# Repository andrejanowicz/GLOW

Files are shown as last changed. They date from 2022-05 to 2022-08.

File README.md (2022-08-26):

# GLOW preamp board for G&L L-2000 and L-2500 Tribute basses

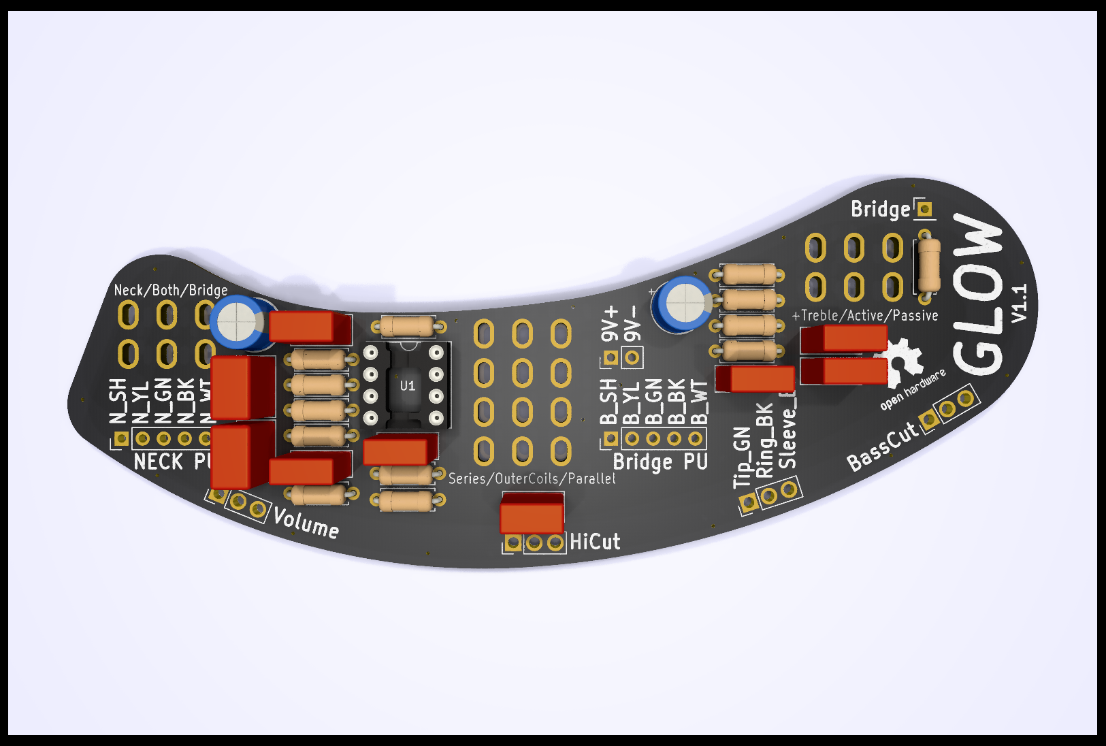
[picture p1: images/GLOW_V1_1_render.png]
</br>

### you might now the situation

>You’re at band rehearsal, playing your beautiful L2000 in active mode with crisp treble boost (that's how its done, right?), as you notice the dreaded hissing of a dying battery. You switch to passive mode with the swiftness of a hungry cheetah, but the guitar player already gives you the look. Of course he has noticed. He always does. You did only pretend to notice the pre CBS mojo of his '62 Strat though. Take that, Mr. all-passive-signal-path.
>
>As the song is done, you put the bass away. No way you’re changing the battery right here on the spot, with all those witnesses. This dirty secret must stay between the L2000 and you, they must not know! They have no idea that this is Leo’s actual masterpiece, not some overpriced 60s guitar. You touch the little switches, toggle them one by one, the click is as satisfying as on the day you brought it home. It takes some time to understand them, sure. To you, they are no mystery. Of course there are a lot of wires needed for all this flexibility, only a fool would not understand that. „Volume - Volume - Tone.. Pathetic!“ you mumble to yourself a little louder than intended. By now the drummer also looks at you. You go home. You wait until everybody is asleep and start silently searching for the screwdriver. You bite your tongue as you open the electronics compartment. You just can’t stand that mess. This instrument deserves better. You change the battery, put the bass aside and check to what dimensions the lead time for Wal MK2‘s has grown by now. You drool over that sweet, clean and well organized electronics box, that PCB: per-fec-tion. If you only bought one eight years ago, when you had the chance. While contemplating live decisions you hear a soft voice: Is everything okay, honey? It’s late, are you looking at bass guitars on the internet again? "Damn right I am, and I think I might have a plan" you say as you look up without blinking your eyes.

## Features

- single PCB with elegant black soldermask
- directly connected toggle switches, no extra wires
- additional single coil setting using only outer coils (K-Mod)
- original preamp circuitry using highest quality components:
- Wima MKP/FKP foil capacitors, Panasonic FC electrolytic capacitors, Yageo 1% resistors
- compatible with original LM4250 or alternatively TL061 op-amps
- fully open source KiCad project (CC BY-NC-SA 4.0)
- fits Tribute models made in Korea and Indonesia (no guarantee)
- banana shaped

## PCB top
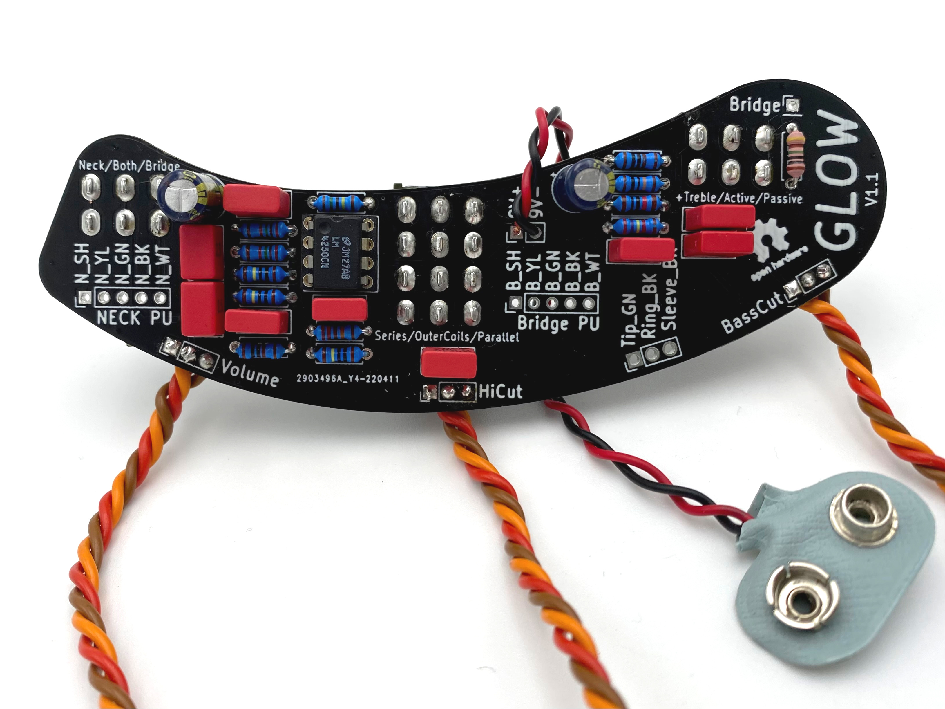
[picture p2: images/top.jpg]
</br>
## PCB bottom
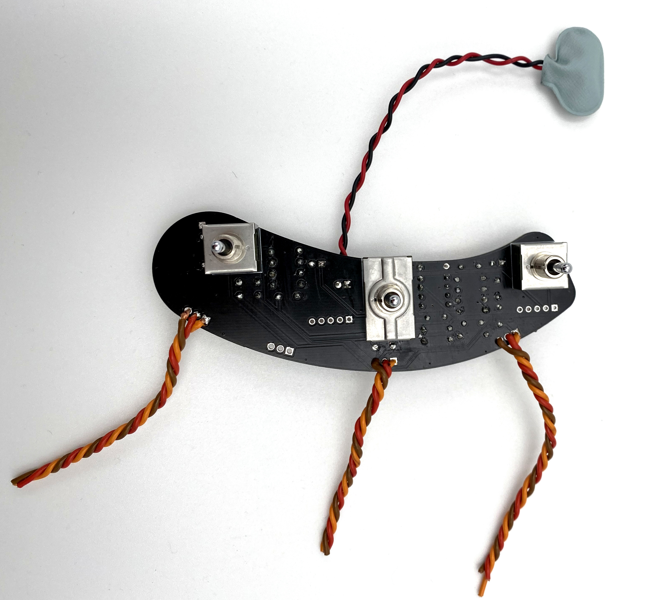
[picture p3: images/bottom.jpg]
</br>
## installed
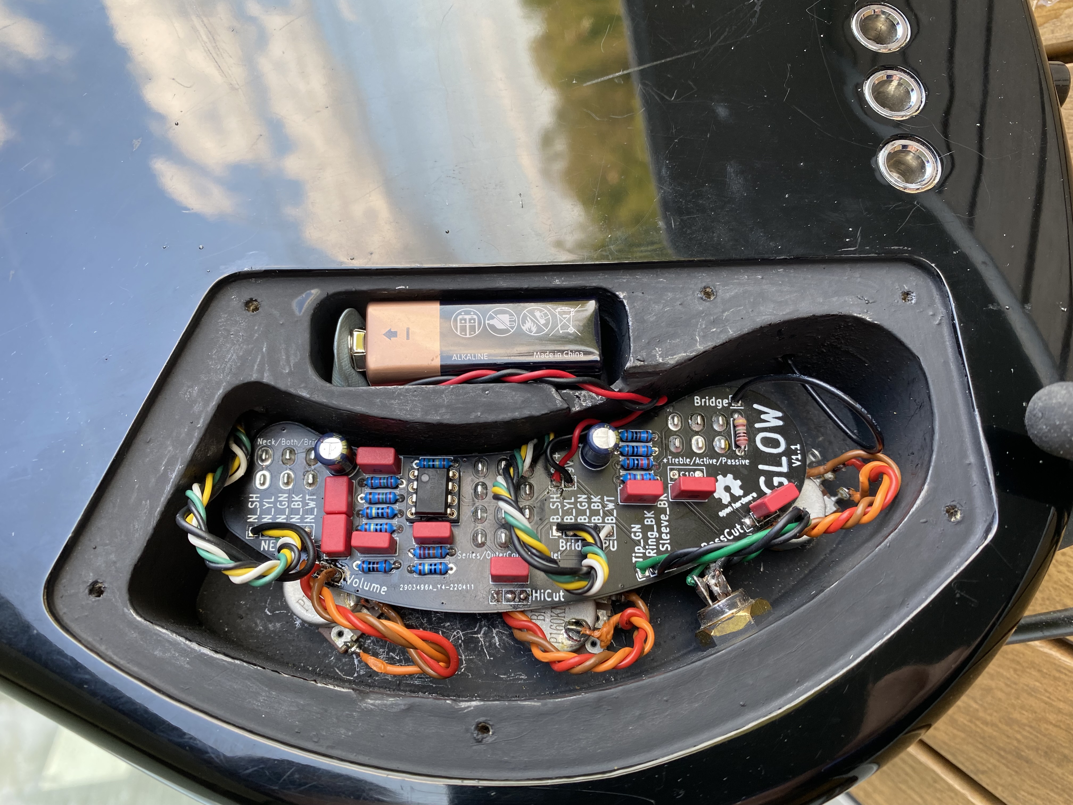
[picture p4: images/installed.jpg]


I give absolutely no guarantee that the PCB and most important the position of the toggle switches will fit your bass. Glow was succesfully installed by me and others in four and five string indonesian and korean Tribute models (L-2000 and L-2500). Fit in USA models is unknown. It does <b>not</b> fit models with sheet metal cover on front/knob side. 
The stock 24mm pots are interfering with GLOW PCB and you need to use 16mm pots with at least 7mm thread length. For more information see BOM document.

## Drill hole position check
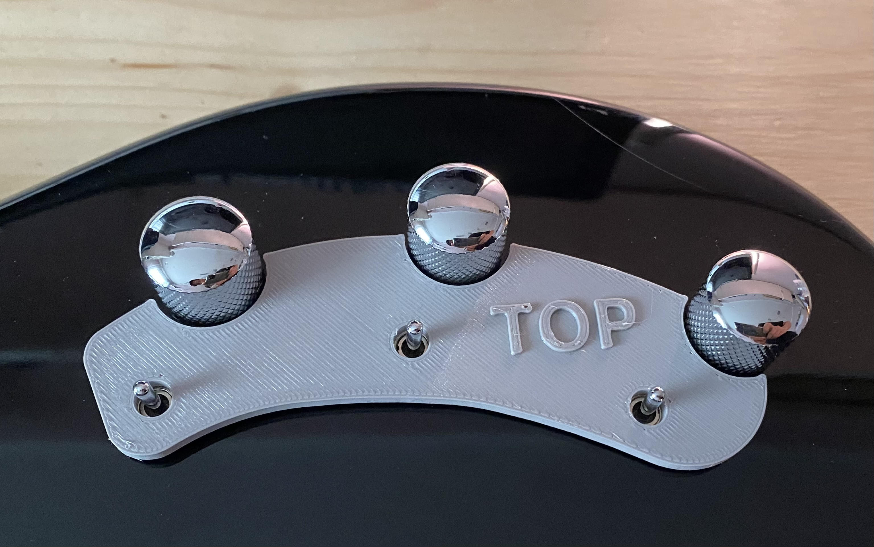
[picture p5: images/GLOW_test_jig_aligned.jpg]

You can upfront assess the fit by 3D printing GLOW_test_jig.stl and align the jig with the position of your toggle switches.

## Thanks
This project would have been much harder without the extensive information found on [bassesbyleo.com](https://www.bassesbyleo.com/) .

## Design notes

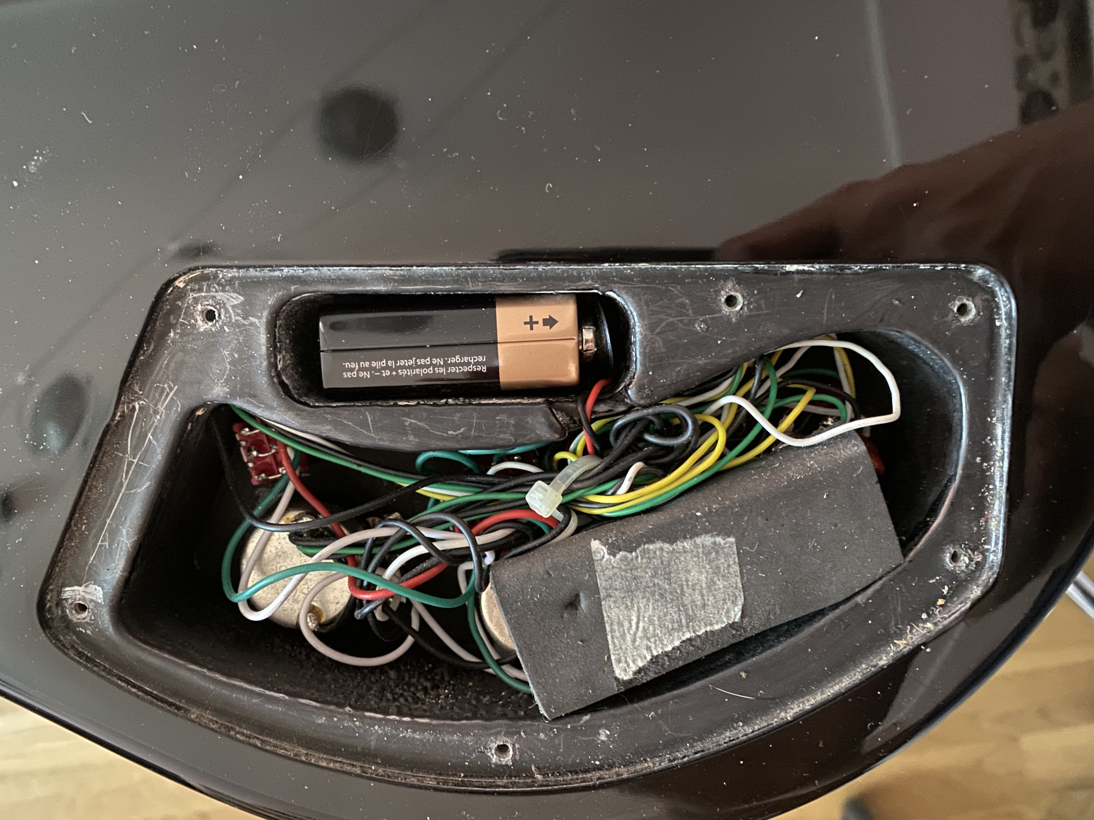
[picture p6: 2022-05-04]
images/before.jpg

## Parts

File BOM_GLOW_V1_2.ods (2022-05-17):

Date: | Wed 04 May 2022 04:34:23 PM CEST
Tool: | Eeschema 6.0.4-6f826c9f35~116~ubuntu20.04.1
Generator: | /usr/share/kicad/plugins/bom_csv_grouped_by_value_with_fp.py
Component Count: | 31
Ref | Qnty | Value | Cmp name | Footprint | Description | Vendor
C1, C8, | 2 | C_Polarized 10uF | C_Polarized | Capacitor_THT:CP_Radial_D6.3mm_P2.50mm | Polarized capacitor | Panasonic | EEU-FC2A100B
C2, | 1 | 220p | C | Capacitor_THT:C_Rect_L7.2mm_W4.5mm_P5.00mm_FKS2_FKP2_MKS2_MKP2 | Unpolarized capacitor | WIMA | FKP2D002201D00HSSD
C3, | 1 | 220p ( originally 200p) | C | Capacitor_THT:C_Rect_L7.2mm_W4.5mm_P5.00mm_FKS2_FKP2_MKS2_MKP2 | Unpolarized capacitor | WIMA | FKP2D002201D00HSSD
C4, C7, | 2 | 47n | C | Capacitor_THT:C_Rect_L7.2mm_W3.5mm_P5.00mm_FKS2_FKP2_MKS2_MKP2 | Unpolarized capacitor | WIMA | MKP2D024701C00JO00
C5, | 1 | 10n | C | Capacitor_THT:C_Rect_L7.2mm_W3.0mm_P5.00mm_FKS2_FKP2_MKS2_MKP2 | Unpolarized capacitor | WIMA | MKP2D021001B00JC00
C6, C10, | 2 | 1n | C | Capacitor_THT:C_Rect_L7.2mm_W3.0mm_P5.00mm_FKS2_FKP2_MKS2_MKP2 | Unpolarized capacitor | WIMA | MKP2G011001B00JSSD
C9, | 1 | 15n | C | Capacitor_THT:C_Rect_L7.2mm_W3.0mm_P5.00mm_FKS2_FKP2_MKS2_MKP2 | Unpolarized capacitor | WIMA | MKP2D021501B00JSSD
C11, | 1 | 2,2n | C | Capacitor_THT:C_Rect_L7.2mm_W3.0mm_P5.00mm_FKS2_FKP2_MKS2_MKP2 | Unpolarized capacitor | WIMA | MKP2J012201B00KSSD
R1, R2, | 2 | 21.5k | R | Resistor_THT:R_Axial_DIN0207_L6.3mm_D2.5mm_P7.62mm_Horizontal | Resistor | YAGEO | MFR-25FTE-21K5
R3, R4, R8, | 3 | 1M | R | Resistor_THT:R_Axial_DIN0207_L6.3mm_D2.5mm_P7.62mm_Horizontal | Resistor | YAGEO | MFR-25FTE-1M
R5, R9, | 2 | 1k | R | Resistor_THT:R_Axial_DIN0207_L6.3mm_D2.5mm_P7.62mm_Horizontal | Resistor | YAGEO | MFR-25FTE-1K
R6, | 1 | 1.5M | R | Resistor_THT:R_Axial_DIN0207_L6.3mm_D2.5mm_P7.62mm_Horizontal | Resistor | YAGEO | MFR-25FTE-1M5
R7, | 1 | 221K | R | Resistor_THT:R_Axial_DIN0207_L6.3mm_D2.5mm_P7.62mm_Horizontal | Resistor | YAGEO | MFR-25FTE-221K
R10, | 1 | 100k | R | Resistor_THT:R_Axial_DIN0207_L6.3mm_D2.5mm_P7.62mm_Horizontal | Resistor | YAGEO | MFR-25FTE-100K
R11, | 1 | 10K | R | Resistor_THT:R_Axial_DIN0207_L6.3mm_D2.5mm_P7.62mm_Horizontal | Resistor | YAGEO | MFR-25FTE-10K
R12, | 1 | 27.4k | R | Resistor_THT:R_Axial_DIN0207_L6.3mm_D2.5mm_P7.62mm_Horizontal | Resistor | YAGEO | MFR-25FTE-27K4
R13, | 1 | 10M | R | Resistor_THT:R_Axial_DIN0207_L6.3mm_D2.5mm_P7.62mm_Horizontal | Resistor | YAGEO | MFR-25FTE-10M
S1, S3, | 2 | 2PDT ON,ON,ON | 2PDT ON,ON,ON | Switch_toggle:DPDT M2044SS1W01 | Toggle Switch | NKK Switches | M2024SS1W01
S2, | 1 | 4PDT ON,ON,ON | 4PDT ON,ON,ON | G&L:4PDT M2044SS1W01 | Toggle Switch | NKK Switches | M2044SS1W01
U1, | 1 | LM4250 | LM4250 | Package_DIP:DIP-8_W7.62mm_Socket | Programmable Operational Amplifier, DIP-8/SOIC-8 | National Semiconductor | LM4250
Volume | 1 | A250k |  |  | Volume pot | Bourns | PDB181-GTR01-254A2
HiCut | 1 | A250k |  |  | HighCut pot | Bourns | PDB181-GTR01-254A2
BassCut | 1 | B500K |  |  | BassCut pot | Bourns | PDB181-GTR01-504B0

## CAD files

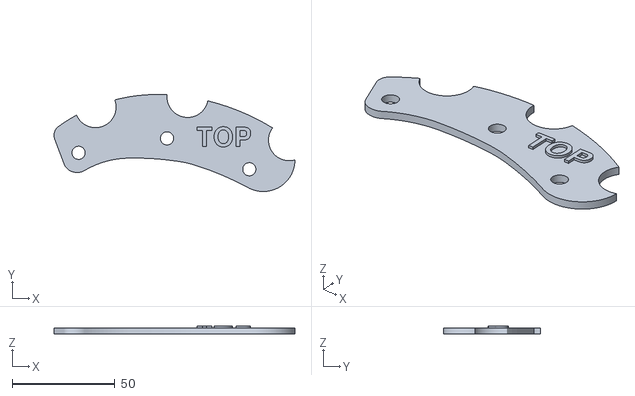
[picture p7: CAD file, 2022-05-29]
GLOW_test_jig.stl
117.1 x 47.2 x 4.00

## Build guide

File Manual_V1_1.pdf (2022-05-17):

GLOW V1.1 Assembly Manual P 1/15 - github.com/andrejanowicz/glow

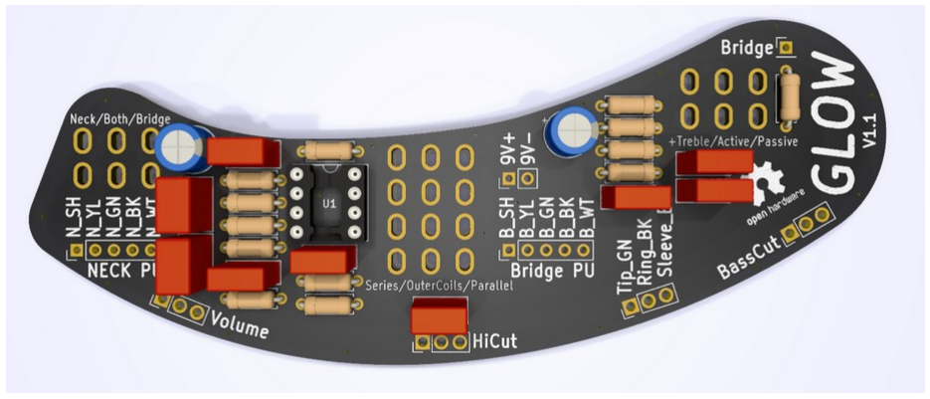
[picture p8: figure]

## Connection overview

PCB | connect to | color
N_SH | Neck cavity shield | black
N_YL | Neck pickup upper coil start | yellow
N_GN | Neck pickup upper coil finish | green
N_BK | Neck pickup lower coil finish | black
N_WT | Neck pickup lower coil start | white
B_SH | Bridge cavity shield | black
B_YL | Bridge pickup upper coil start | yellow
B_GN | Bridge pickup upper coil finish | green
B_BK | Bridge pickup lower coil finish | black
B_WT | Bridge pickup lower coil start | white
Tip_GN | Audio jack tip | green
Ring_BK | Audio jack ring | black
Sleeve_BK | Audio jack sleeve | black
9V+ | Battery positive | red
9V- | Battery negative | black
Bridge | Bridge ground | black
Volume 1 | Pot A250K / A500K pin 1 | orange
Volume 2 | Pot A250K / A500K pin 2 | red
Volume 3 | Pot A250K / A500K pin 3 + housing | brown
HiCut 1 | Pot A250K / A500K housing | orange
HiCut 2 | Pot A250K / A500K pin 2 | red
HiCut 3 | Pot A250K / A500K pin 3 | brown
BassCut 1 | Pot C500K / B500K pin 1 | orange
BassCut 2 | Pot C500K / B500K pin 2 | red
BassCut 3 | Pot C500K / B500K housing | brown

GLOW V1.1 Assembly Manual P 2/15

## PCB fit test

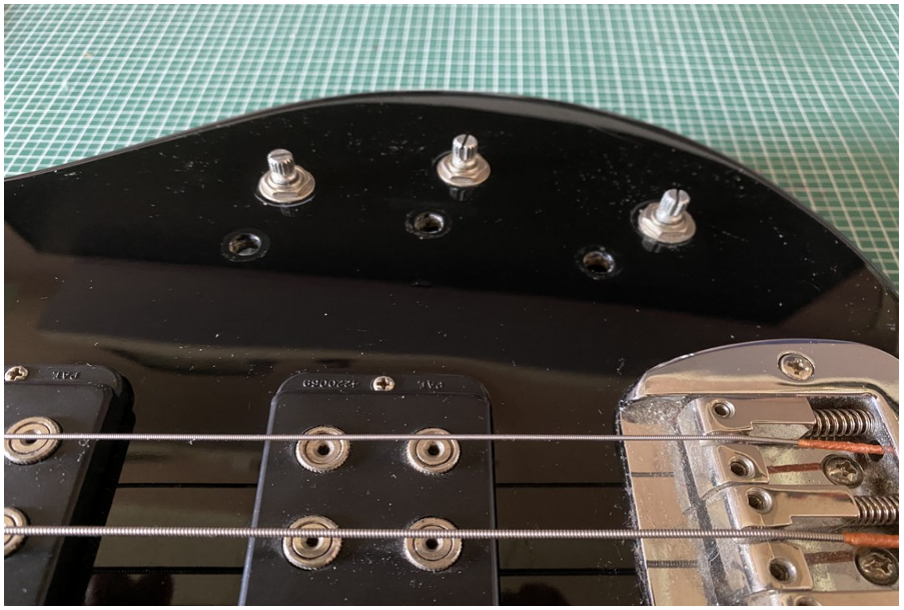
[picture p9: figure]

Illustration 1: remove knobs on all three pots. Unscrew the nuts of the three toggle switches and push toggle switches into the electronics compartment.

GLOW V1.1 Assembly Manual P 3/15

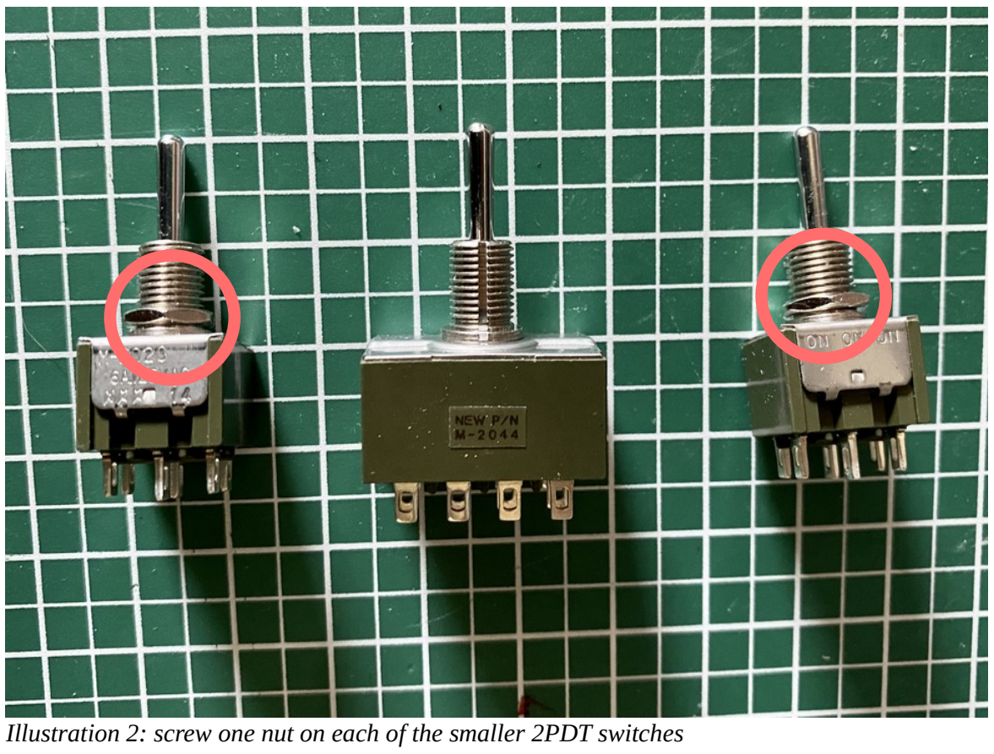
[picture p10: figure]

Illustration 2: screw one nut on each of the smaller 2PDT switches

GLOW V1.1 Assembly Manual P 4/15

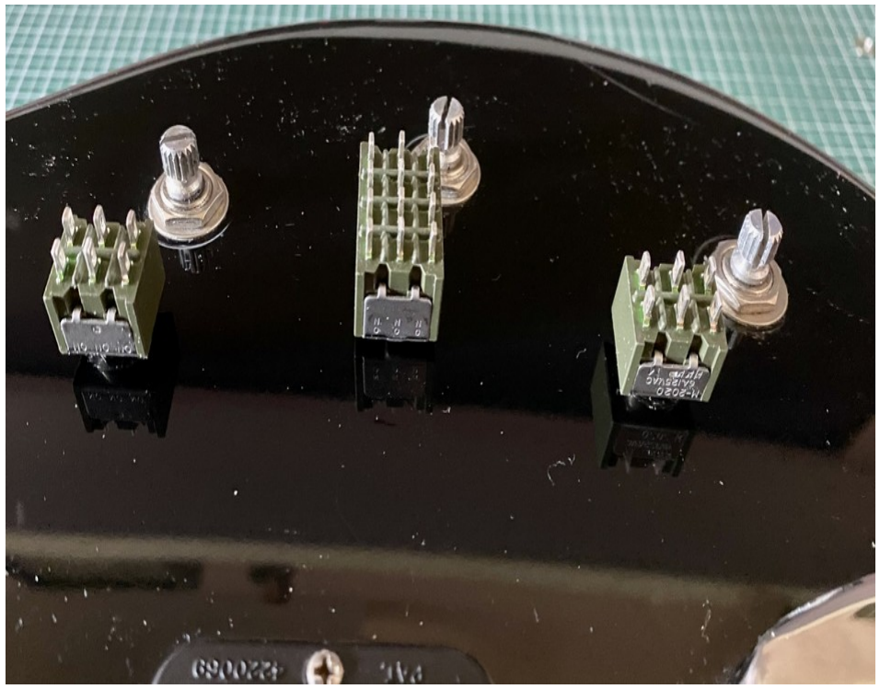
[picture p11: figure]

Illustration 3: stick toggle switches into the holes on the front

GLOW V1.1 Assembly Manual P 5/15

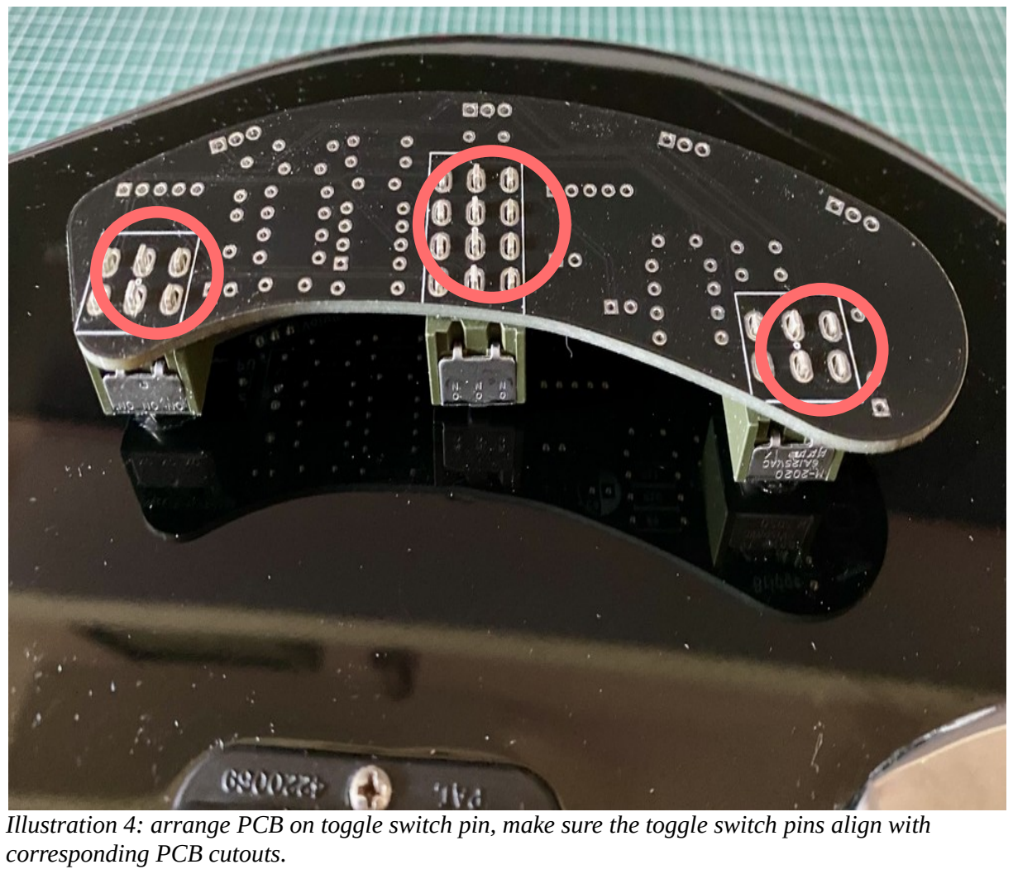
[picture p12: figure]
corresponding PCB cutouts.

Illustration 4: arrange PCB on toggle switch pin, make sure the toggle switch pins align with

If it looks like picture above, GLOW will most likely fit your bass.

I do not give any guarantee or take any responsibility for any changes or damage you do to your instrument. Please keep in mind that this is not a simple procedure or easy reversible modification.

GLOW is provided as is. There is no warranty.
You proceed on your own risk.

GLOW V1.1 Assembly Manual P 6/15

## Assembly

## switches

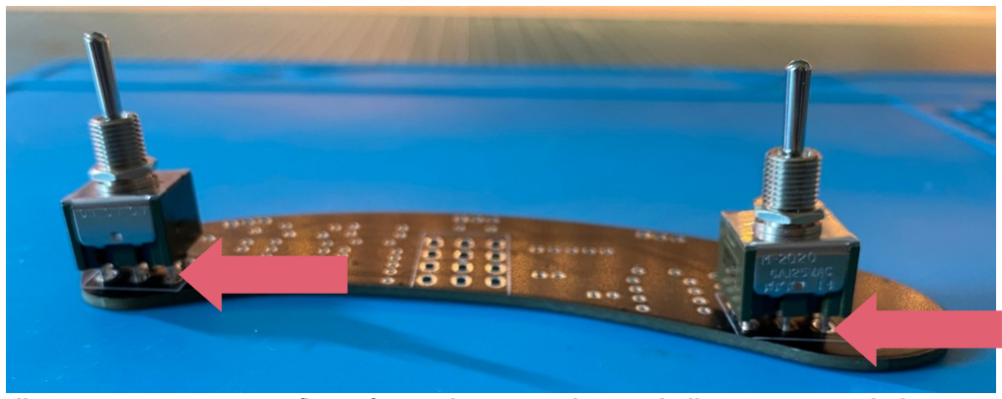
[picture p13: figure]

Illustration 5: Lay PCB on a flat surface, with “GLOW” logo and silkscreen prints to the bottom. Stick 2 x 2PDT toggle switches into cutouts on PCB. Solder a single connection to one of the pins on each toggle switch from the top with the PCB still flat on the surface. There should be a distance of about 2-3mm between switch bottom and PCB. After soldering, carefully bend the switch to a upright position, if needed.

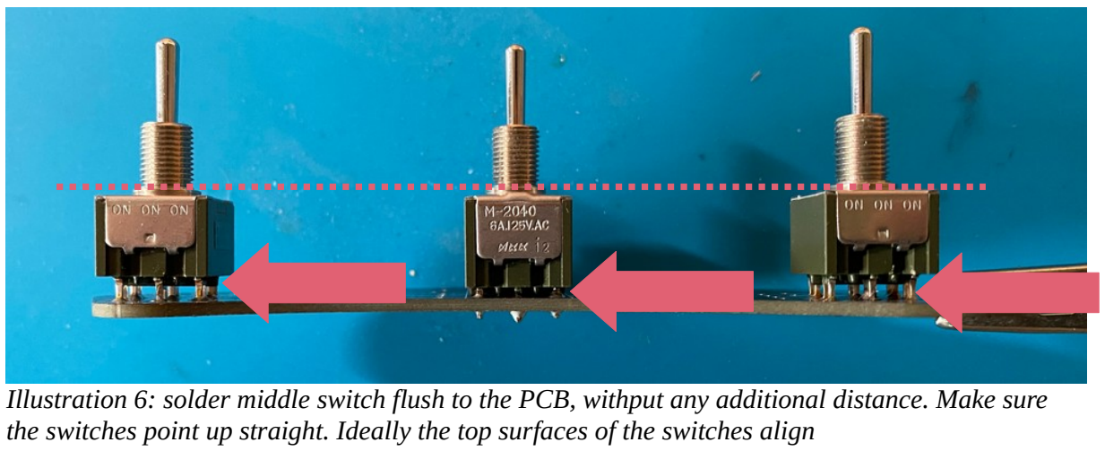
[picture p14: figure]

Illustration 6: solder middle switch flush to the PCB, withput any additional distance. Make sure the switches point up straight. Ideally the top surfaces of the switches align

GLOW V1.1 Assembly Manual P 7/15

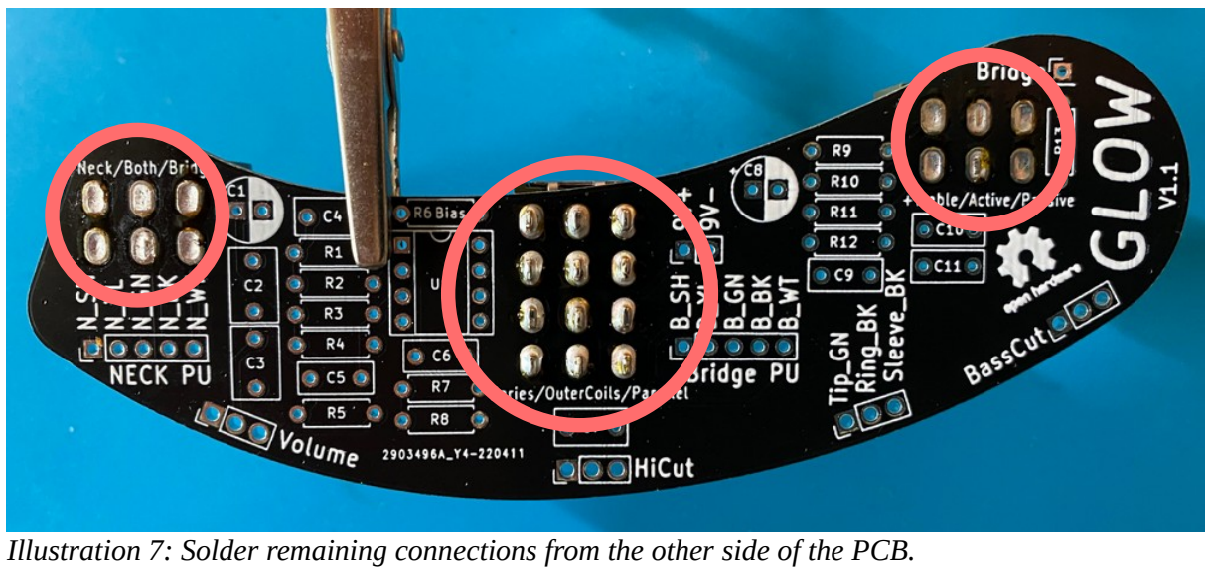
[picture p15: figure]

Illustration 7: The middle switch should not have any distance to the board. This is crucial to compensate for different height of the switch housings.

Illustration 7: Solder remaining connections from the other side of the PCB.

GLOW V1.1 Assembly Manual P 8/15

## Components

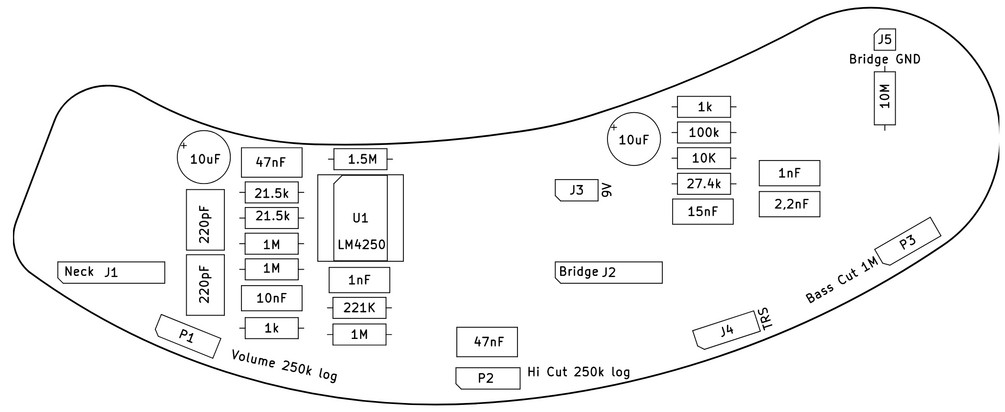
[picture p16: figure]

Solder smallest components first. Start with Resistors R1 to R13. Afterwards socket U1, solder capacitors C1 to C11 last.

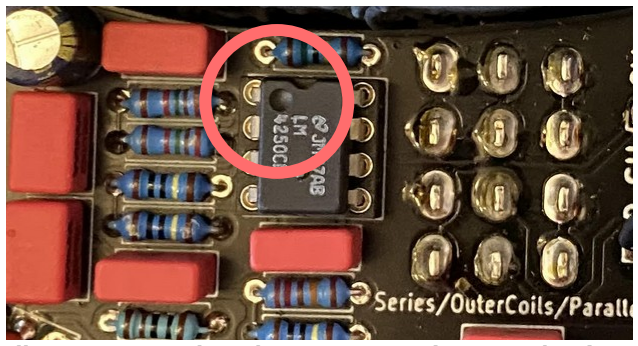
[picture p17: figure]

Illustration 8: gently push op amp into socket U1, with indent pointing upwards

## V1.1 Fix

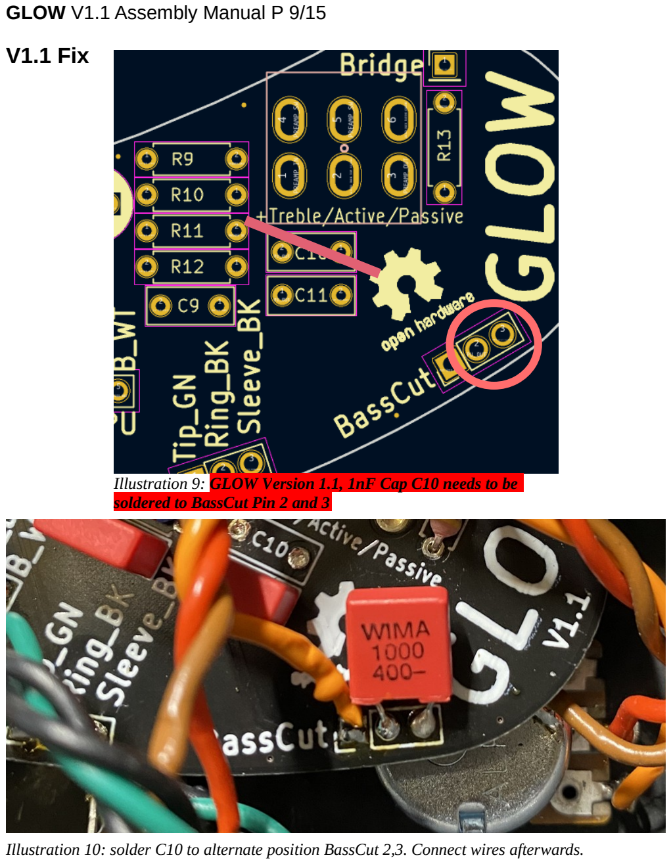
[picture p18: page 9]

GLOW V1.1 Assembly Manual P 9/15

Illustration 10: solder C10 to alternate position BassCut 2,3. Connect wires afterwards.

Illustration 9: GLOW Version 1.1, 1nF Cap C10 needs to be soldered to BassCut Pin 2 and 3

## Pots

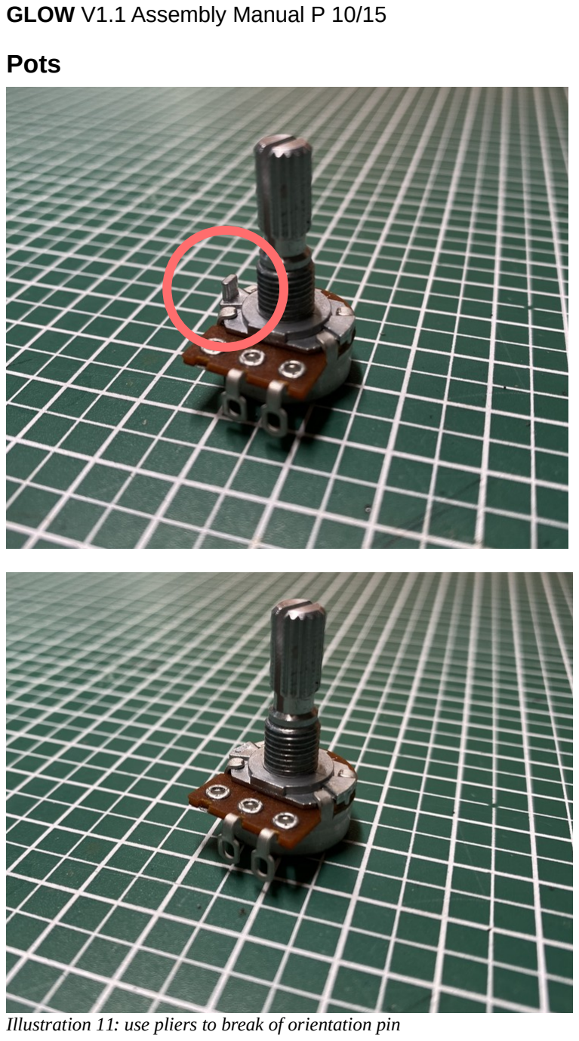
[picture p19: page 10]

GLOW V1.1 Assembly Manual P 10/15

Illustration 11: use pliers to break of orientation pin

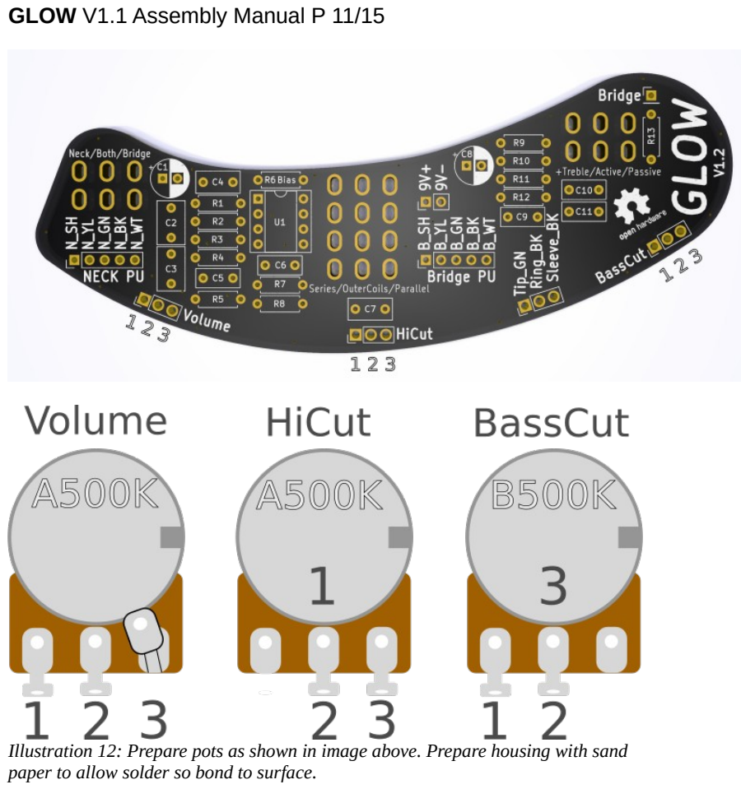
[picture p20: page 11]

GLOW V1.1 Assembly Manual P 11/15

Illustration 12: Prepare pots as shown in image above. Prepare housing with sand paper to allow solder so bond to surface.

GLOW V1.1 Assembly Manual P 12/15

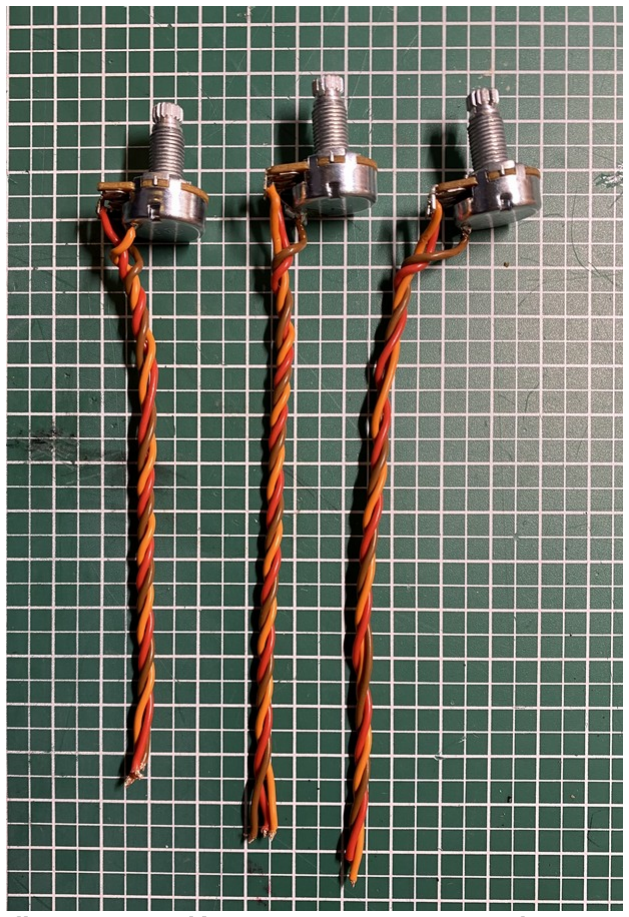
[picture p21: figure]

Illustration 13: solder wires to pots. Twist wire as shown.

Note: Recommended Bourns PDB181-GTR pots with 3/8 NEF (9.525mm) diameter thread might not fit the holes of the previous pots. In this case, carefully drill holes to 10mm. Use painters tape on the outside to prevent scratches and chipping of the paint.

GLOW V1.1 Assembly Manual P 13/15

## Preparation

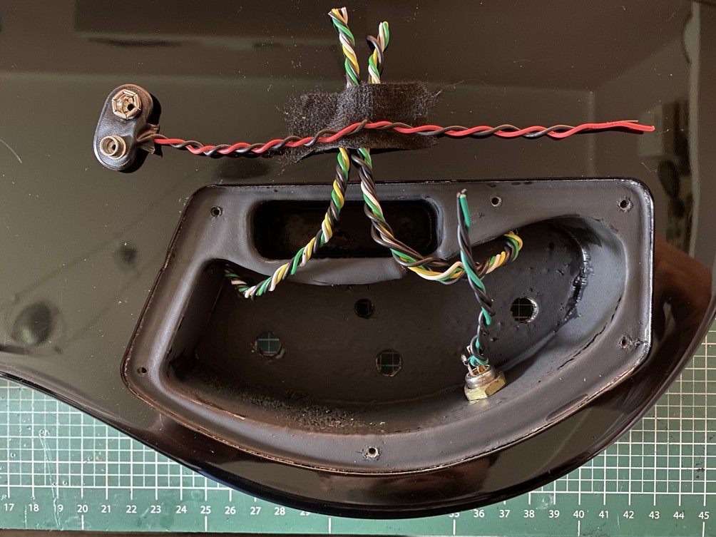
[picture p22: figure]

Illustration 14: remove toggle switches and pots from housing. Cut wires at appropriate lengths. Desolder black battery connector wire from audio jack, solder a black wire to (now unconnected) terminal on audio jack

GLOW V1.1 Assembly Manual P 14/15

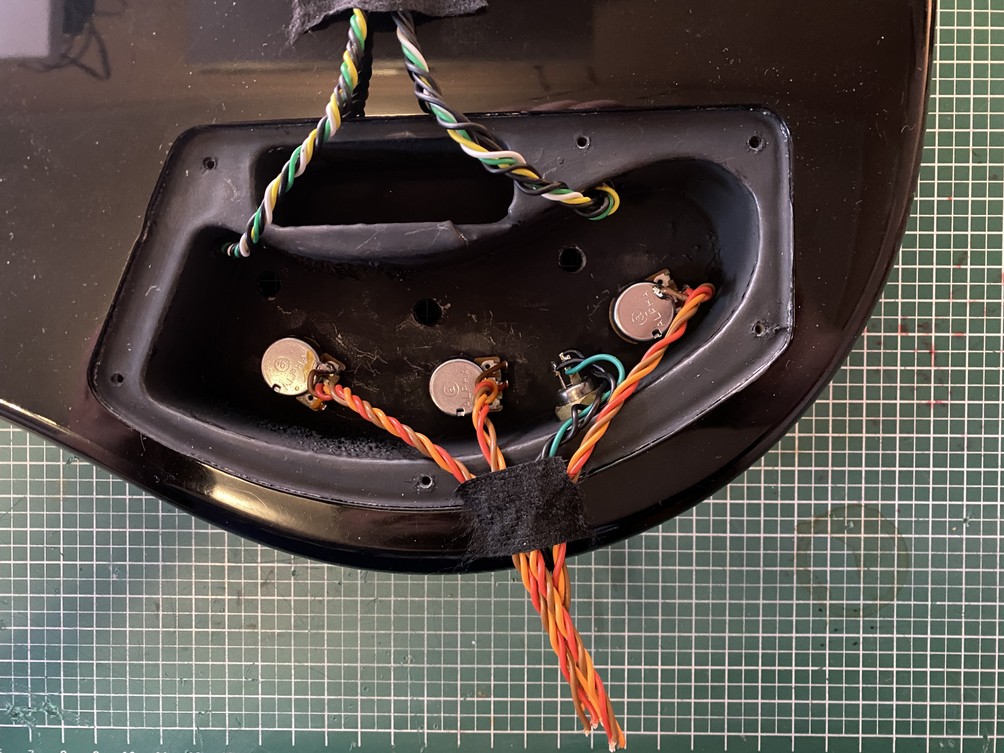
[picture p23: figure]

Illustration 15: Mount Volume, HiCut and BassCut pot to body. Fix nut tightly.

GLOW V1.1 Assembly Manual P 15/15

## Final assembly

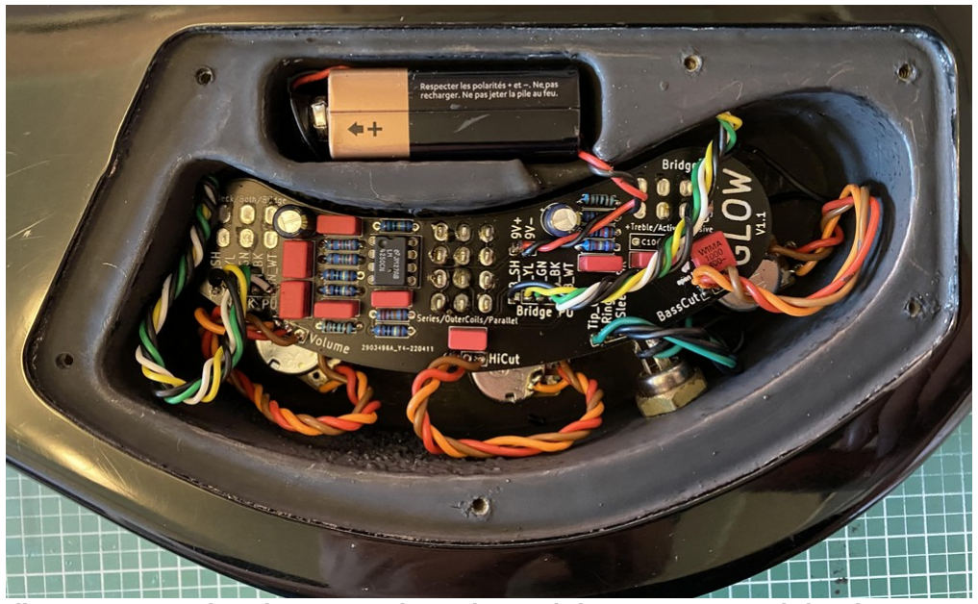
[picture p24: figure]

Illustration 16: Firmly push GLOW toggle switches into holes. Put nuts on switch threads. Screw nuts tight. It is okay to bend the PCB to a certain degree. Solder pot wires in order 1, 2, 3 starting from left. Solder all other wires to corresponding terminals on GLOW PCB.

# Enjoy!

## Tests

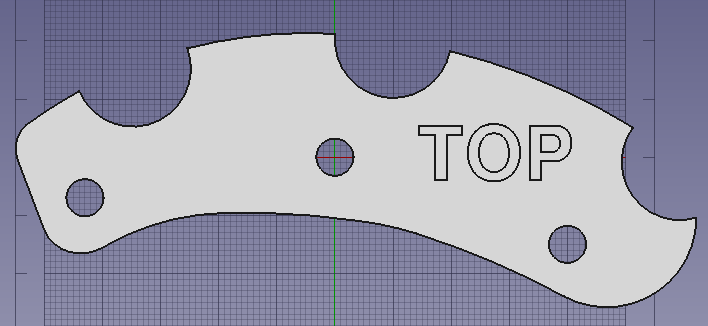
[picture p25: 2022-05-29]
images/GLOW_test_jig.png

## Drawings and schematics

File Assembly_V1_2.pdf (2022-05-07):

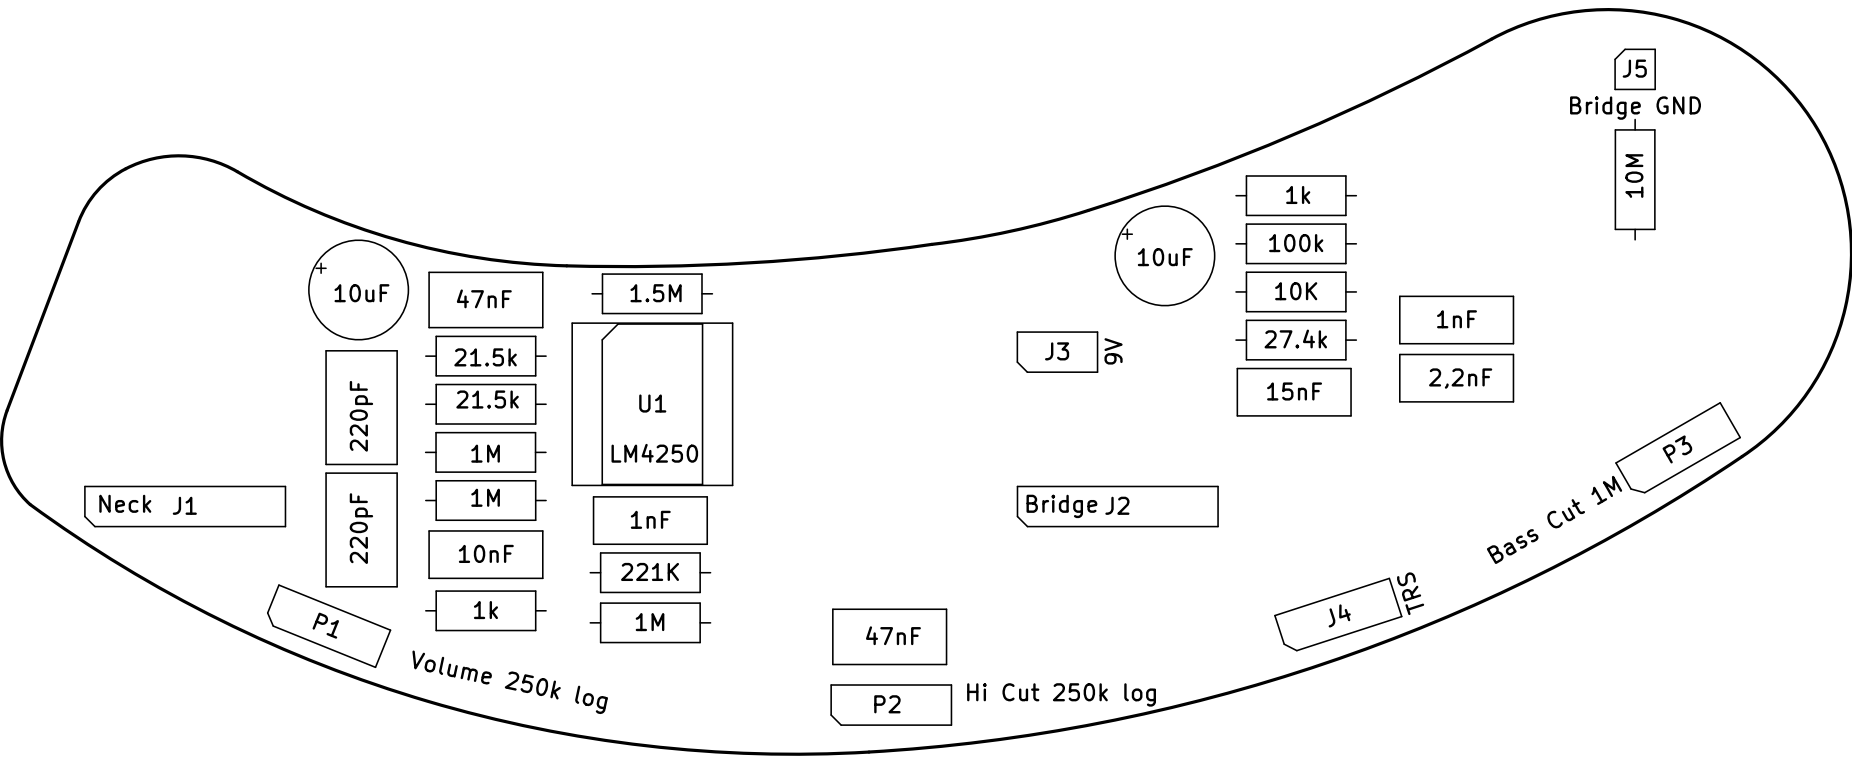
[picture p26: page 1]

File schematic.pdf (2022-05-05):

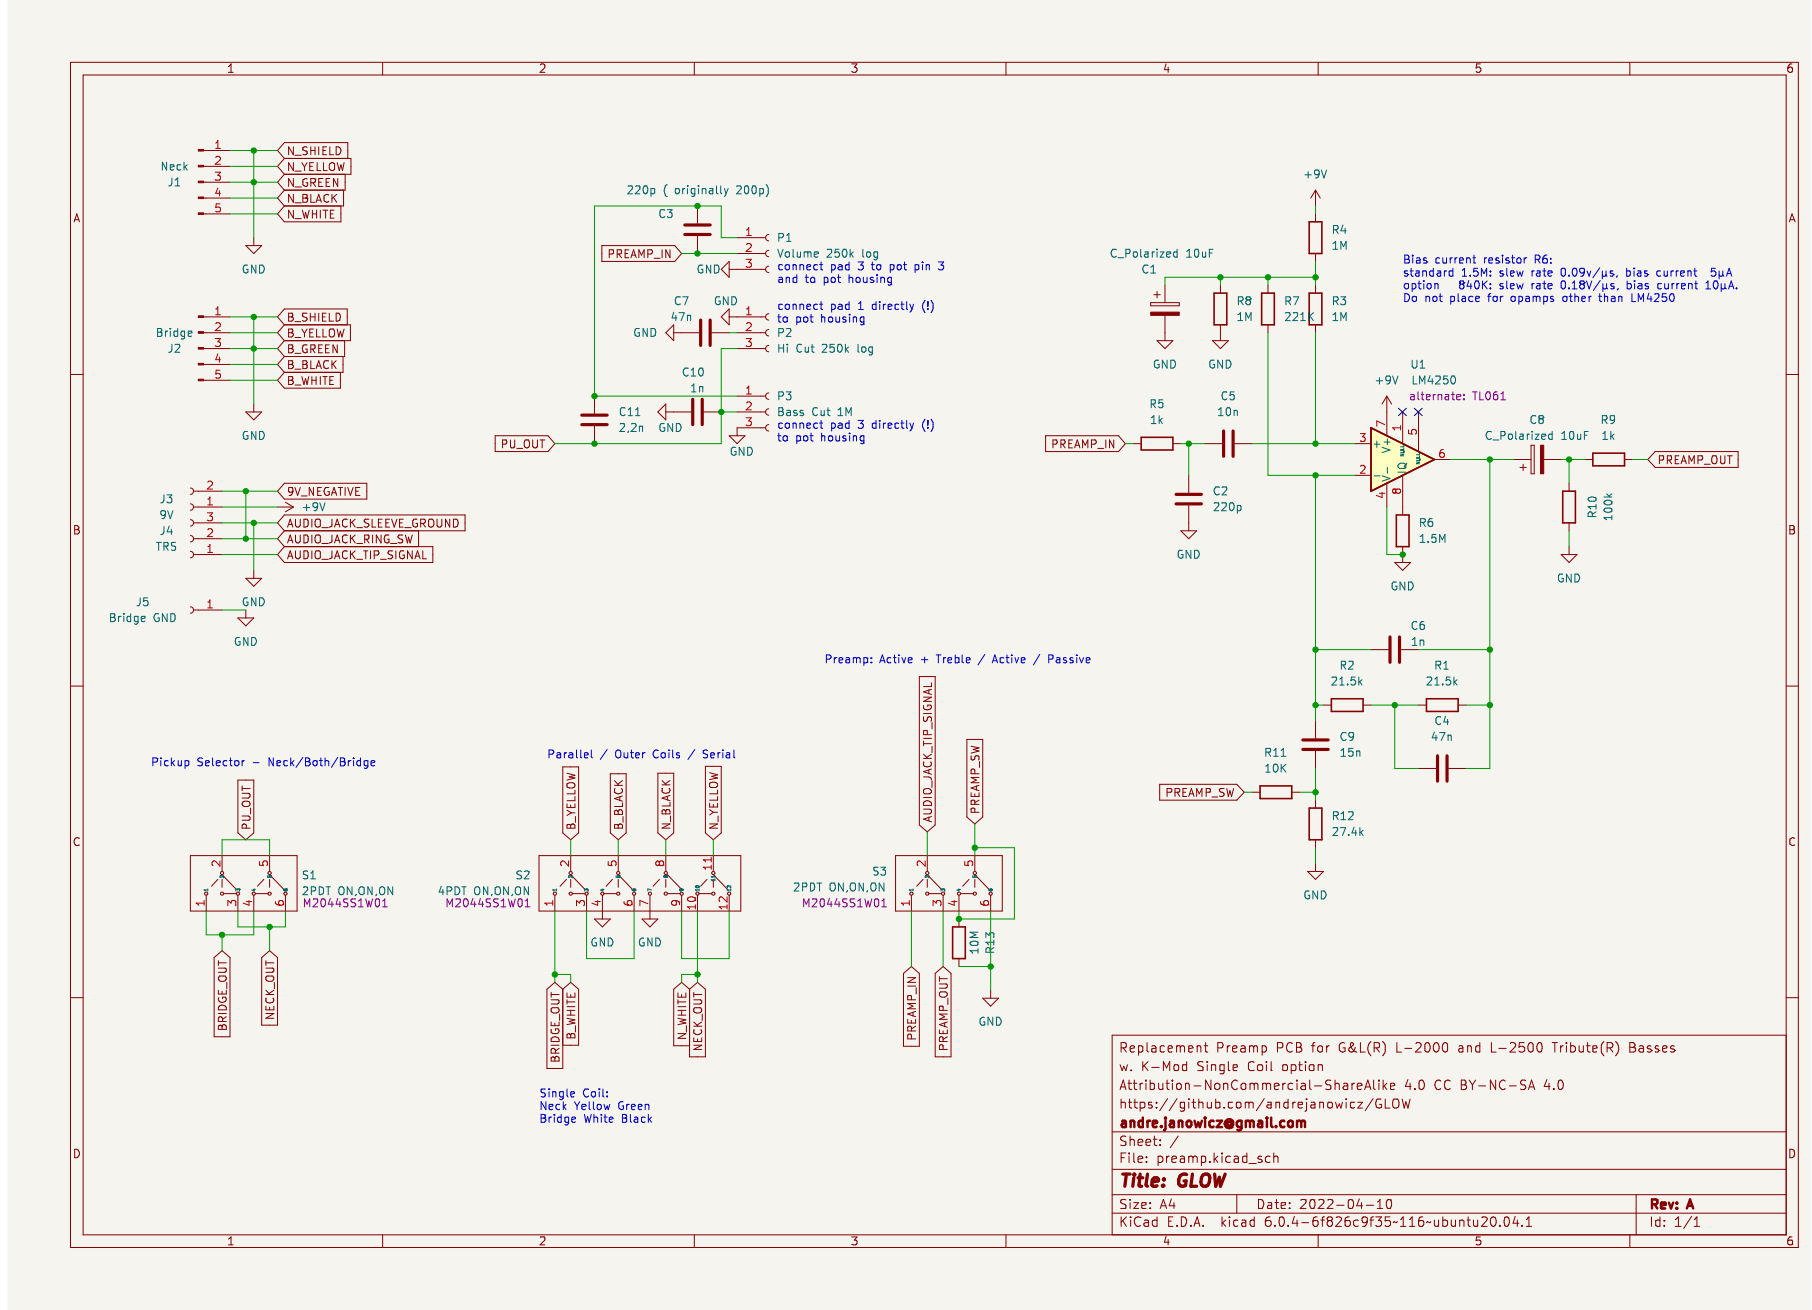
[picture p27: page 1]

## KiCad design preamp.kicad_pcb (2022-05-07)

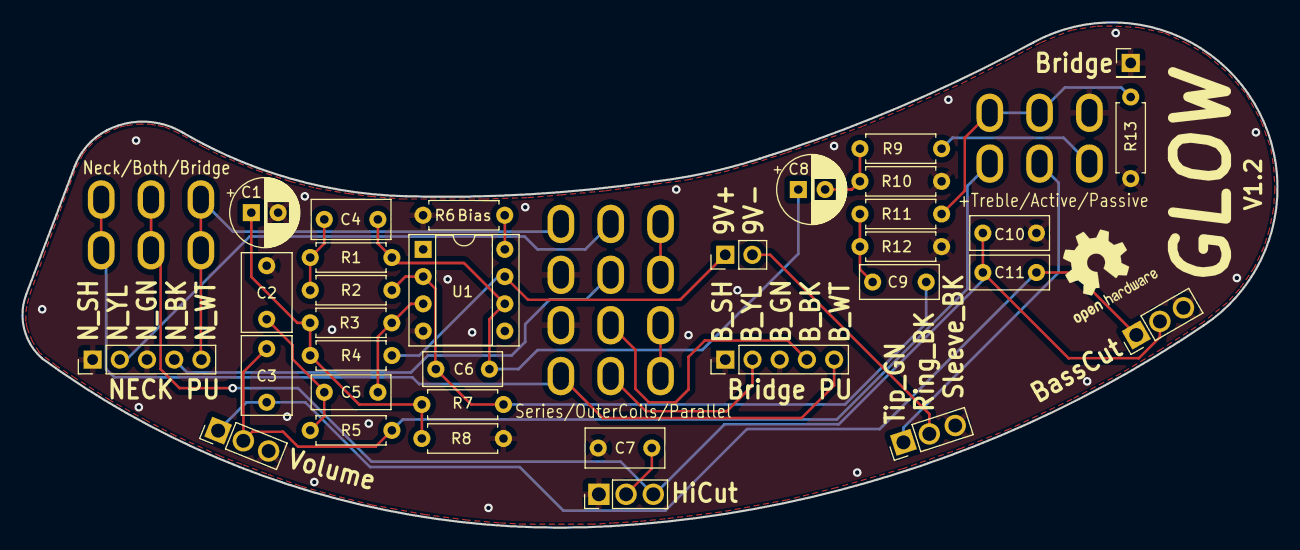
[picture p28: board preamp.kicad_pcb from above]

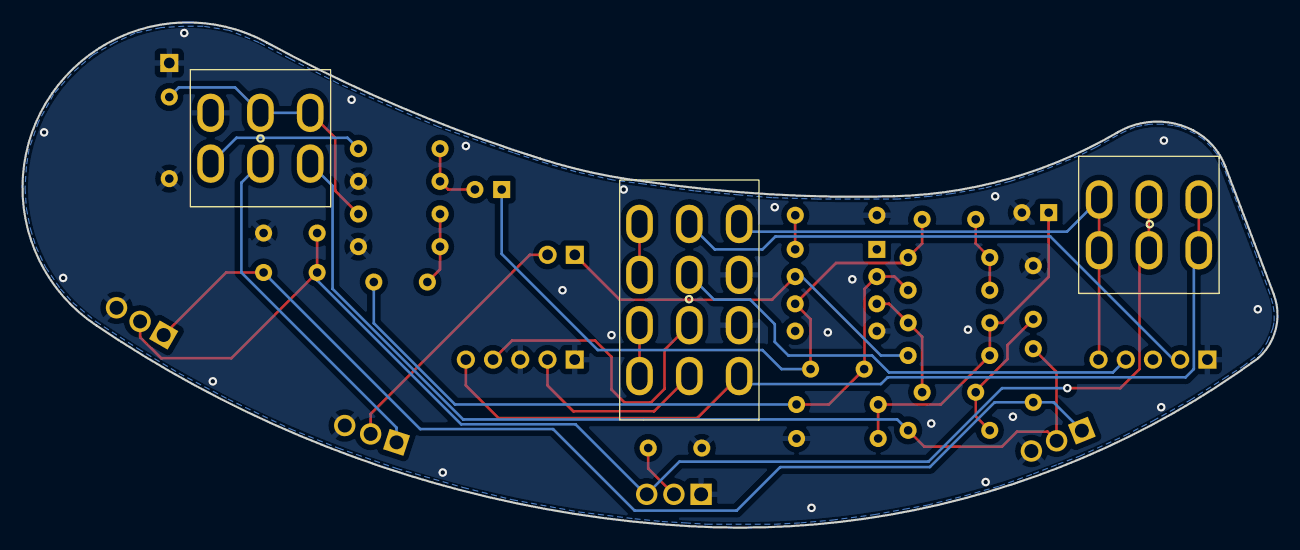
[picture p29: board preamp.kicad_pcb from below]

Board: 2 copper layers, 117.1 x 47.1 mm, 36 parts (3 on the bottom side), 27 nets.

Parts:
C1, C8: 10uF; CP_Radial_D6.3mm_P2.50mm
C2, C3: 220pF; C_Rect_L7.2mm_W4.5mm_P5.00mm_FKS2_FKP2_MKS2_MKP2
C4, C7: 47nF; C_Rect_L7.2mm_W3.5mm_P5.00mm_FKS2_FKP2_MKS2_MKP2
C5: 10nF; C_Rect_L7.2mm_W3.0mm_P5.00mm_FKS2_FKP2_MKS2_MKP2
C6, C10: 1nF; C_Rect_L7.2mm_W3.0mm_P5.00mm_FKS2_FKP2_MKS2_MKP2
C9: 15nF; C_Rect_L7.2mm_W3.0mm_P5.00mm_FKS2_FKP2_MKS2_MKP2
C11: 2,2nF; C_Rect_L7.2mm_W3.0mm_P5.00mm_FKS2_FKP2_MKS2_MKP2
J1: Neck; PinHeader_1x05_P2.54mm_Vertical
J2: Bridge; PinHeader_1x05_P2.54mm_Vertical
J3: 9V; PinHeader_1x02_P2.54mm_Vertical
J4: TRS; PinHeader_1x03_P2.54mm_Vertical
J5: Bridge GND; PinHeader_1x01_P2.54mm_Vertical
P1: Volume 250k log; PinHeader_1x03_P2.54mm_Vertical
P2: Hi Cut 250k log; PinHeader_1x03_P2.54mm_Vertical
P3: Bass Cut 1M; PinHeader_1x03_P2.54mm_Vertical
R1, R2: 21.5k; R_Axial_DIN0207_L6.3mm_D2.5mm_P7.62mm_Horizontal
R3, R4, R8: 1M; R_Axial_DIN0207_L6.3mm_D2.5mm_P7.62mm_Horizontal
R5, R9: 1k; R_Axial_DIN0207_L6.3mm_D2.5mm_P7.62mm_Horizontal
R6: 1.5M; R_Axial_DIN0207_L6.3mm_D2.5mm_P7.62mm_Horizontal
R7: 221K; R_Axial_DIN0207_L6.3mm_D2.5mm_P7.62mm_Horizontal
R10: 100k; R_Axial_DIN0207_L6.3mm_D2.5mm_P7.62mm_Horizontal
R11: 10K; R_Axial_DIN0207_L6.3mm_D2.5mm_P7.62mm_Horizontal
R12: 27.4k; R_Axial_DIN0207_L6.3mm_D2.5mm_P7.62mm_Horizontal
R13: 10M; R_Axial_DIN0207_L6.3mm_D2.5mm_P7.62mm_Horizontal
S1, S3: 2PDT ON,ON,ON; DPDT M2044SS1W01
S2: 4PDT ON,ON,ON; 4PDT M2044SS1W01
U1: LM4250; DIP-8_W7.62mm_Socket

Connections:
9V_NEGATIVE: J3.2, J4.2
+9V: J3.1, R4.1, U1.7 (V+)
AUDIO_JACK_SLEEVE_GROUND: C1.2, C2.1, C7.2, C10.1, J1.1, J1.3, J2.1, J2.3, J4.3, J5.1, P1.3, P2.1, P3.3, R6.2, R8.2, R10.1, R12.1, R13.1, S2.4, S2.7, S3.6, U1.4 (V-)
AUDIO_JACK_TIP_SIGNAL: J4.1, S3.2
BRIDGE_OUT: J2.5, S1.1, S1.4, S2.1
B_BLACK: J2.4, S2.5
B_YELLOW: J2.2, S2.2
NECK_OUT: J1.5, S1.3, S1.6, S2.10
N_BLACK: J1.4, S2.8
N_YELLOW: J1.2, S2.11
unnamed: C1.1, R3.1, R4.2, R7.1, R8.1
unnamed: C2.2, C5.1, R5.2
unnamed: C4.1, C6.1, C8.1, R1.2, U1.6
unnamed: C4.2, R1.1, R2.2
unnamed: C5.2, R3.2, U1.3 (+)
unnamed: C6.2, C9.1, R2.1, R7.2, U1.2 (-)
unnamed: C7.1, P2.2
unnamed: C8.2, R9.1, R10.2
unnamed: C9.2, R11.1, R12.2
unnamed: C3.2, C11.2, P1.1, P3.1
unnamed: R6.1, U1.8 (IQ)
unnamed: S2.3, S2.6
unnamed: S2.9, S2.12
PREAMP_IN: C3.1, P1.2, R5.1, S3.1
PREAMP_OUT: R9.2, S3.3
PREAMP_SW: R11.2, R13.2, S3.4, S3.5
PU_OUT: C10.2, C11.1, P2.3, P3.2, S1.2, S1.5

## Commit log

2022-05-04 inital commit
    [BOM_GLOW_V1_2.ods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]
2022-05-04 PCB bottom and top view
2022-05-04 added 16mm pots to BOM
    [BOM_GLOW_V1_2.ods]
2022-05-05 added PDF of schematic
2022-05-07 cleaned up Fab layers
    [preamp.kicad_pcb]
2022-05-07 Revert "cleaned up Fab layers"
    This reverts commit a53a61183b3b20636eedd4e96066f84f9d1e0d9c.
    [preamp.kicad_pcb]
2022-05-07 added assembly drawing
2022-05-17 updated BOM, included new pots
    [BOM_GLOW_V1_2.ods]
2022-05-29 added test jig
    [GLOW_test_jig.stl]

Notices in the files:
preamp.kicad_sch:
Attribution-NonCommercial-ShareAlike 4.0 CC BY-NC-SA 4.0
